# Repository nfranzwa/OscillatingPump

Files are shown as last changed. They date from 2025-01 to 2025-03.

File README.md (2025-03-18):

UCSD MAE 156 Capstone Project

The provided code was developed using Arduino IDE and the Platform.io extension on VS Code.
While it is possible to flash/deploy our software to an ESP32 through other means, we heavily recommend the two for ease of installing dependencies and following subsequent instructions.

# Setup
In order to flash the GPIO ESP or Web ESP, first make a local copy of the most recent version of this repository by clicking `<Code>` and either:

 - Copying and running the command in terminal (requires github cli installation or git)
 - Opening through Github Desktop (requires installing the Github Desktop app)
 - Downloading and extracting the code from a .zip file

The next steps assume you have a local copy of the provided code.

# Installing Libraries

## GPIO ESP

Click the Platform IO icon on the left edge of VS Code, then navigate to `Quick Access > PIO Home > Projects & Configuration`.



Select `Add Existing`.



Navigate to the directory `drive/path/to/repository/OscillatingPump/ESP32_CTRL` and select `Open "ESP32_CTRL`.



Shortly, Platform IO should be setting up the project according to the `platform.ini` file in the selected folder, most importantly installing libraries that are used in the project.

## Web ESP

Open the Arduino sketch named `webesp.ino` located in `/WebappCode/webesp/webesp/`.

Navigate to the library manager.



Search for and install the following libraries:
 - Arduino_JSON by Arduino
 - Async TCP by ESP32Async
 - ESP Async WebServer by ESP32ASync
 - EspSoftwareSerial by Dirk Kaar, Peter Lerup

In the top menu, Navigate to `Sketch > Include Library`, and include the following:
 - WiFi
 - LittleFS



The next step is to install ESP32 LittleFS uploader to the Arduino IDE.

Go to [[https://github.com/earlephilhower/arduino-littlefs-upload/releases]] and download the latest version of `arduino-littlefs-upload-x.x.x.vsix`.

Windows: 
1. In File Explorer, navigate to `C:\Users\<username>\.arduinoIDE\`
2. Create a folder called `plugins` if it doesn't already exist.
3. Move the downloaded `.vsix` file into this folder.

Mac OS: 
1. In Finder, navigate to `~/.arduinoIDE`
2. Create a new folder called `plugins`
3. Move the downloaded `.vsix` file into this folder.

Restart the Arduino IDE, and make sure the plug-in was successfully installed by opening the command palette with `Ctrl/Cmd + Shift + P` and ensuring `Upload LittleFS to Pico/ESP8266/ESP32` is an available command.

# Uploading/Deploying code to the ESP32's

With the environments and libraries set up, one can compile and deploy the code through the following procedures.

## GPIO ESP

On the bottom bar, ensure that the Platform IO project is ESP32_CTRL and you are deploying to the right COM port (leave as `Auto` unless multiple ESP's are connected to same computer).



The code will be compiled and deployed to the ESP32 when pressing the `→` button.
 - one can also compile the code without deploying by pressing the `✓` button.

A new terminal should open within VS Code, displaying compile messages. When the terminal says `Connecting...`
Press and hold the `Boot` button on the ESP until the terminal shows that code is being written to the ESP32.

## Web ESP
First, Go to `Sketch > Show Sketch Folder` and ensure that the `data/` folder from our repository is there. This contains files that are to be uploaded to the ESP32 filesystem.

Open the command palette and run `Upload LittleFS to Pico/ESP8266/ESP32`.

After getting a `Completed upload` message, compile and deploy the sketch to the ESP32 by pressing the `→` button.
 - one can also compile the code without deploying by pressing the `✓` button.

When the terminal says `Connecting...`
Press and hold the `Boot` button on the ESP until the terminal shows that code is being written to the ESP32.

# Troubleshooting code
If the ESP's are consistently not behaving as expected, we provide debugging statements through Serial Monitors, which can be accessed through the Command Palette of both VS Code and Arduino IDE.

Issues to check may include whether an ESP is:
 - constantly restarting (stuck in a boot loop)
 - unable to communicate through serial with the other ESP
 - some particular features are not behaving as expected
 - error codes being thrown by an ESP

The GPIO ESP has an ongoing task that reads the Serial port between the computer and ESP, providing the user with the following inputs and features:

| User Input | Feature |
| --- | --- |
| `debug` | toggles debugging statements for Serial communication between ESPs |
| `cal debug` | toggles debugging statements for during calibration |
| `wave debug` | toggles debugging statements for wave generation |
| `show pm` | prints out the current pressure map vector |
| `m:#.## M:#.##` | manually overwrite the target min and max pressure |
| `c:#` | manually overwrite the calibration state |

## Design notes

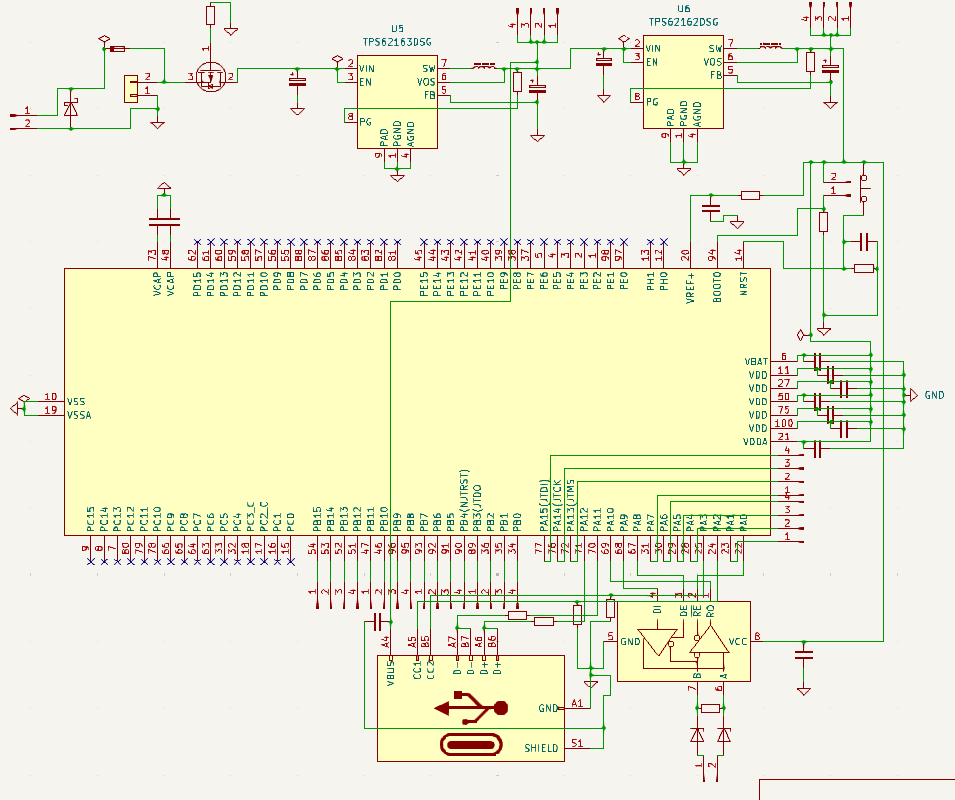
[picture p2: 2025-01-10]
Media/PCB_Schematic.PNG

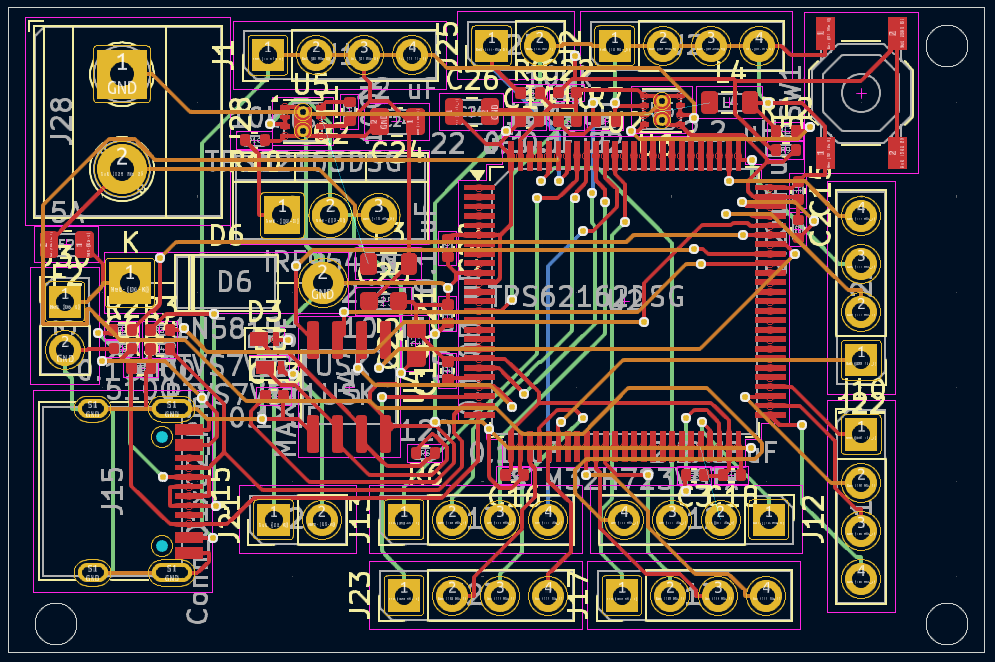
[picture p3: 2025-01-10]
Media/PCB_Layout.PNG

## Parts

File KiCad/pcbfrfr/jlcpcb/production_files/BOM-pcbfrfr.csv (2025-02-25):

Comment | Designator | Footprint | LCSC | Quantity
1000 uF | C5 | CP_Radial_D10.0mm_P5.00mm | C10750 | 1
Barrel_Jack_Switch | J1 | BarrelJack_CLIFF_FC681465S_SMT_Horizontal | C113716 | 1
0.001 uF | C11 | C_0402_1005Metric | C1523 | 1
4.7 uH | L1,L3 | L_Changjiang_FXL0530 | C177246 | 2
AP63205WU | U2 | TSOT-23-6 | C2071056 | 1
SS24 | D1,D3 | D_SMA | C2762829 | 2
Conn_01x02_Pin | J2,J21 | PinHeader_1x02_P2.54mm_Vertical | C2897365 | 2
Conn_01x03_Pin | J9 | PinHeader_1x03_P2.54mm_Vertical | C2897366 | 1
Conn_01x05_Pin | J10,J11,J16,J17,J18,J19,J20,J6 | PinHeader_1x05_P2.54mm_Vertical | C2897368 | 8
Conn_01x19_Socket | J3,J4,J5,J7 | PinHeader_1x19_P2.54mm_Vertical | C2897382 | 4
0.1 uF | C12,C13,C2,C6,C7,C8 | C_0402_1005Metric | C307331 | 6
10 uF | C1 | CP_Radial_D4.0mm_P1.50mm | C43351 | 1
22 uF | C10,C3,C4,C9 | C_0805_2012Metric | C45783 | 4
Conn_01x04_Pin | J12,J13,J14,J15,J8 | PinHeader_1x04_P2.54mm_Vertical | C5116530 | 5
AP63203WU | U1 | TSOT-23-6 | C780769 | 1

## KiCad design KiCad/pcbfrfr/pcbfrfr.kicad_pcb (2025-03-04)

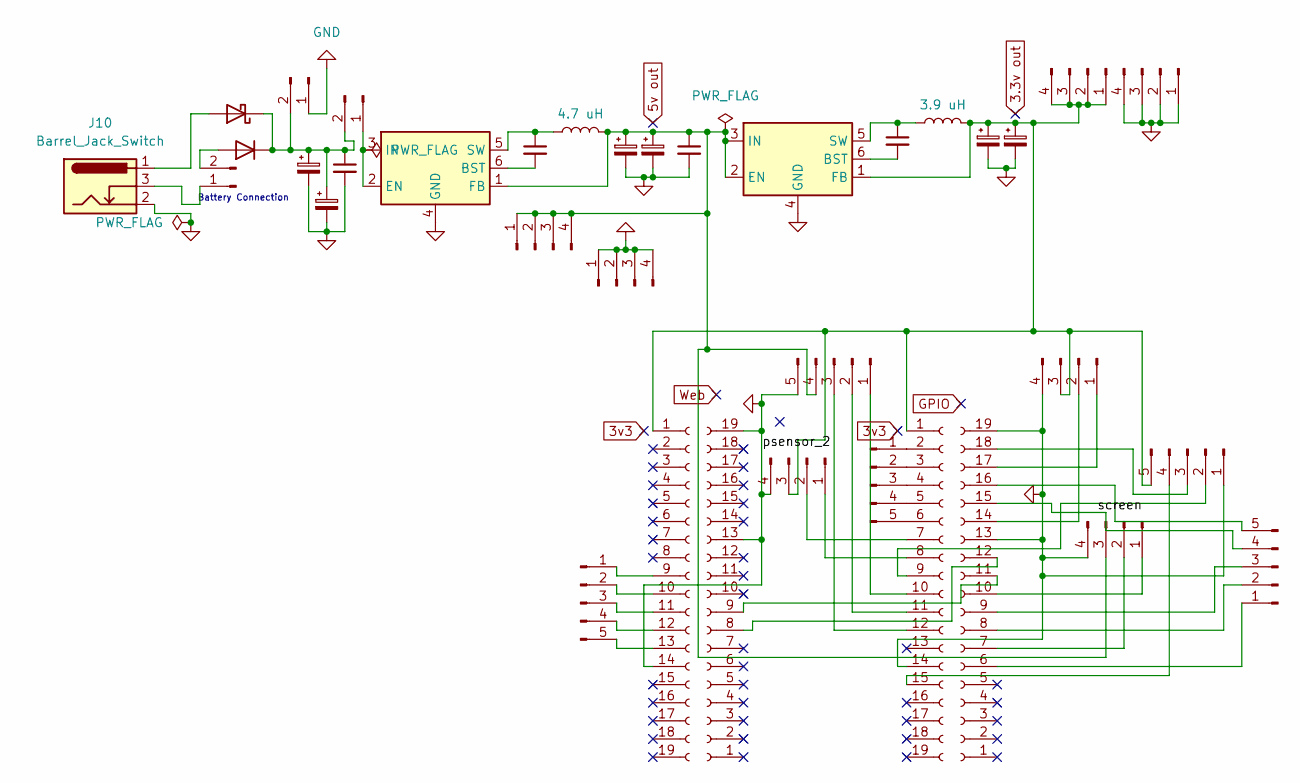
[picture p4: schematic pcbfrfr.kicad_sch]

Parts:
C1: 10 uF; CP_Radial_D4.0mm_P1.50mm
C2, C8: 100 nF; C_0402_1005Metric
C3, C4, C9, C10: 22 uF; C_0805_2012Metric
C5: 1000 uF; CP_Radial_D10.0mm_P5.00mm
C6, C7: 0.1 uF; C_0402_1005Metric
D2: US2AA; D_SMA
D3: SS24; D_SMA
J1, J11, J16, J17, J18: Conn_01x05_Pin; PinHeader_1x05_P2.54mm_Vertical
J2: battery; PinHeader_1x02_P2.54mm_Vertical
J3, J4, J5, J7: Conn_01x19_Socket; PinHeader_1x19_P2.54mm_Vertical
J6, J8, J9, J12, J13, J14, J15: Conn_01x04_Pin; PinHeader_1x04_P2.54mm_Vertical
J10: Barrel_Jack_Switch; BarrelJack_CLIFF_FC681465S_SMT_Horizontal
J21: mtr; PinHeader_1x02_P2.54mm_Vertical
J22: estop; PinHeader_1x02_P2.54mm_Vertical
L1: 4.7 uH; L_Changjiang_FXL0530
L3: 3.9 uH; L_Changjiang_FXL0530
U1: AP63203WU; TSOT-23-6
U2: AP63205WU; TSOT-23-6

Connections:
/screen: J5.15, J17.4
GND: C1.2, C3.2, C4.2, C5.2, C6.2, C7.2, C9.2, C10.2, J1.5, J3.14, J4.14, J5.13, J5.19, J6.4, J7.13, J7.19, J8.4, J9.4, J10.2, J11.1, J13.1, J13.2, J13.3, J13.4, J15.1, J15.2, J15.3, J15.4, J21.1, U1.4 (GND), U2.4 (GND)
unnamed: D2.2 (A), J2.2
unnamed: C1.1, C5.1, C6.1, D2.1 (K), D3.1 (K), J21.2, J22.2
unnamed: D3.2 (A), J10.1
unnamed: J1.1, J4.10
unnamed: J1.2, J4.11
unnamed: J1.3, J4.12
unnamed: C3.1, C4.1, C7.1, J1.4, J9.3, J12.1, J12.2, J12.3, J12.4, L1.2, U1.2 (EN), U1.3 (IN), U2.1 (FB)
unnamed: J2.1, J10.3
unnamed: J4.7, J8.2
unnamed: J4.8, J8.1
unnamed: J5.7, J9.2
unnamed: J5.10, J9.1
unnamed: J5.11, J7.9
unnamed: J5.12, J7.8
unnamed: J5.14, J6.2
unnamed: J5.17, J6.1
unnamed: J4.9, J11.2
unnamed: J5.18, J11.3
unnamed: J4.15, J11.4
unnamed: C9.1, C10.1, J3.1, J4.1, J6.3, J8.3, J11.5, J14.1, J14.2, J14.3, J14.4, L3.2, U1.1 (FB)
unnamed: J4.2, J16.1
unnamed: J4.3, J16.2
unnamed: J4.4, J16.3
unnamed: J4.5, J16.4
unnamed: J4.6, J16.5
unnamed: J5.6, J17.1
unnamed: J5.8, J17.2
unnamed: J5.9, J17.3
unnamed: J5.16, J17.5
unnamed: J3.9, J18.1
unnamed: J3.10, J18.2
unnamed: J3.11, J18.3
unnamed: J3.12, J18.4
unnamed: J3.13, J18.5
unnamed: J22.1, U2.2 (EN), U2.3 (IN)
unnamed: C8.2, U1.6 (BST)
unnamed: C8.1, L3.1, U1.5 (SW)
unnamed: C2.2, U2.6 (BST)
unnamed: C2.1, L1.1, U2.5 (SW)

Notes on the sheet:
Battery Connection

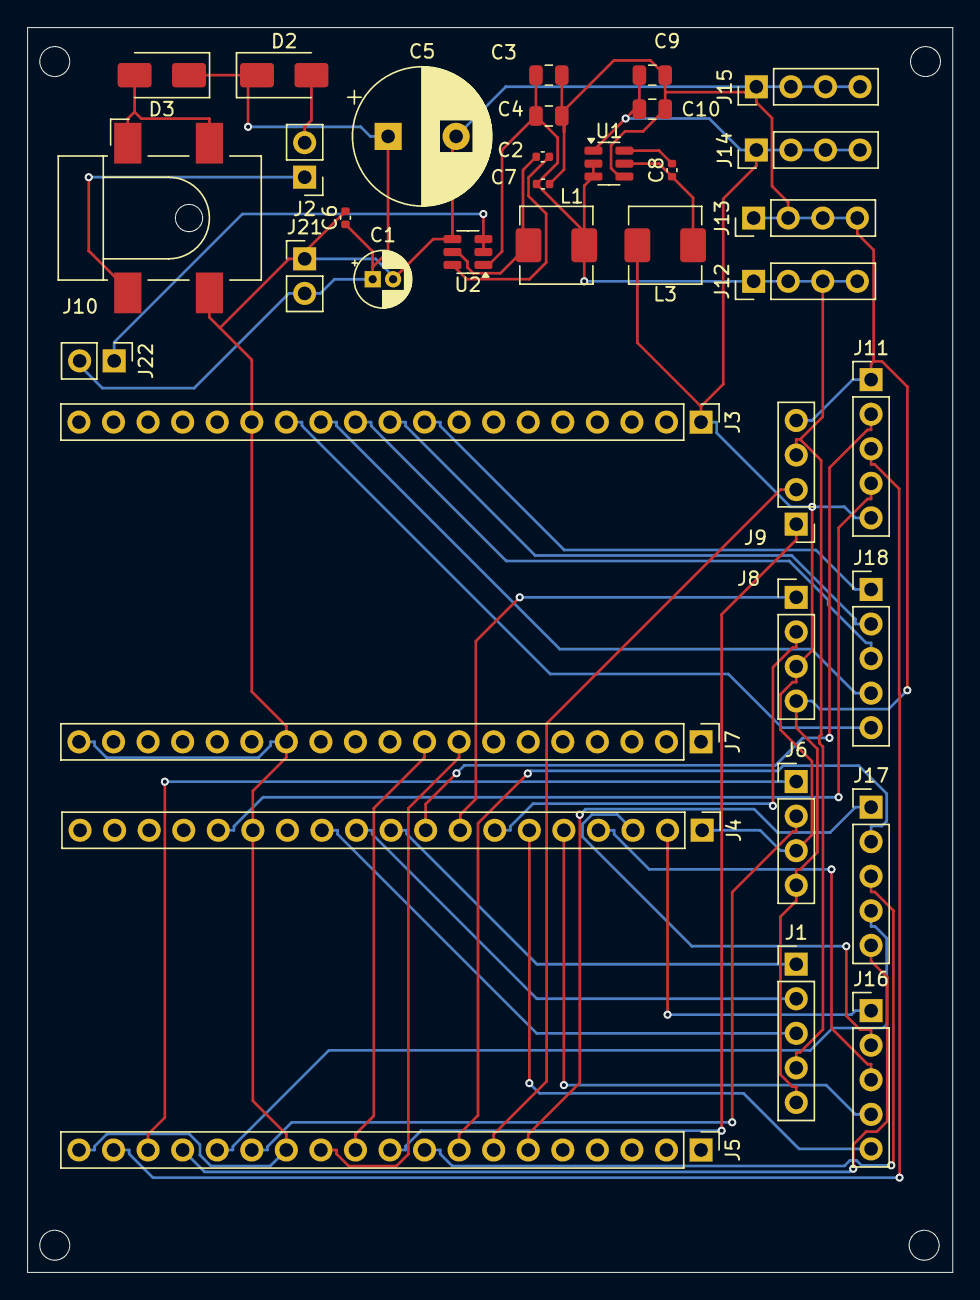
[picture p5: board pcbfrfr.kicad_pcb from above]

Board: 2 copper layers, 68.0 x 91.5 mm, 36 parts (0 on the bottom side), 41 nets.

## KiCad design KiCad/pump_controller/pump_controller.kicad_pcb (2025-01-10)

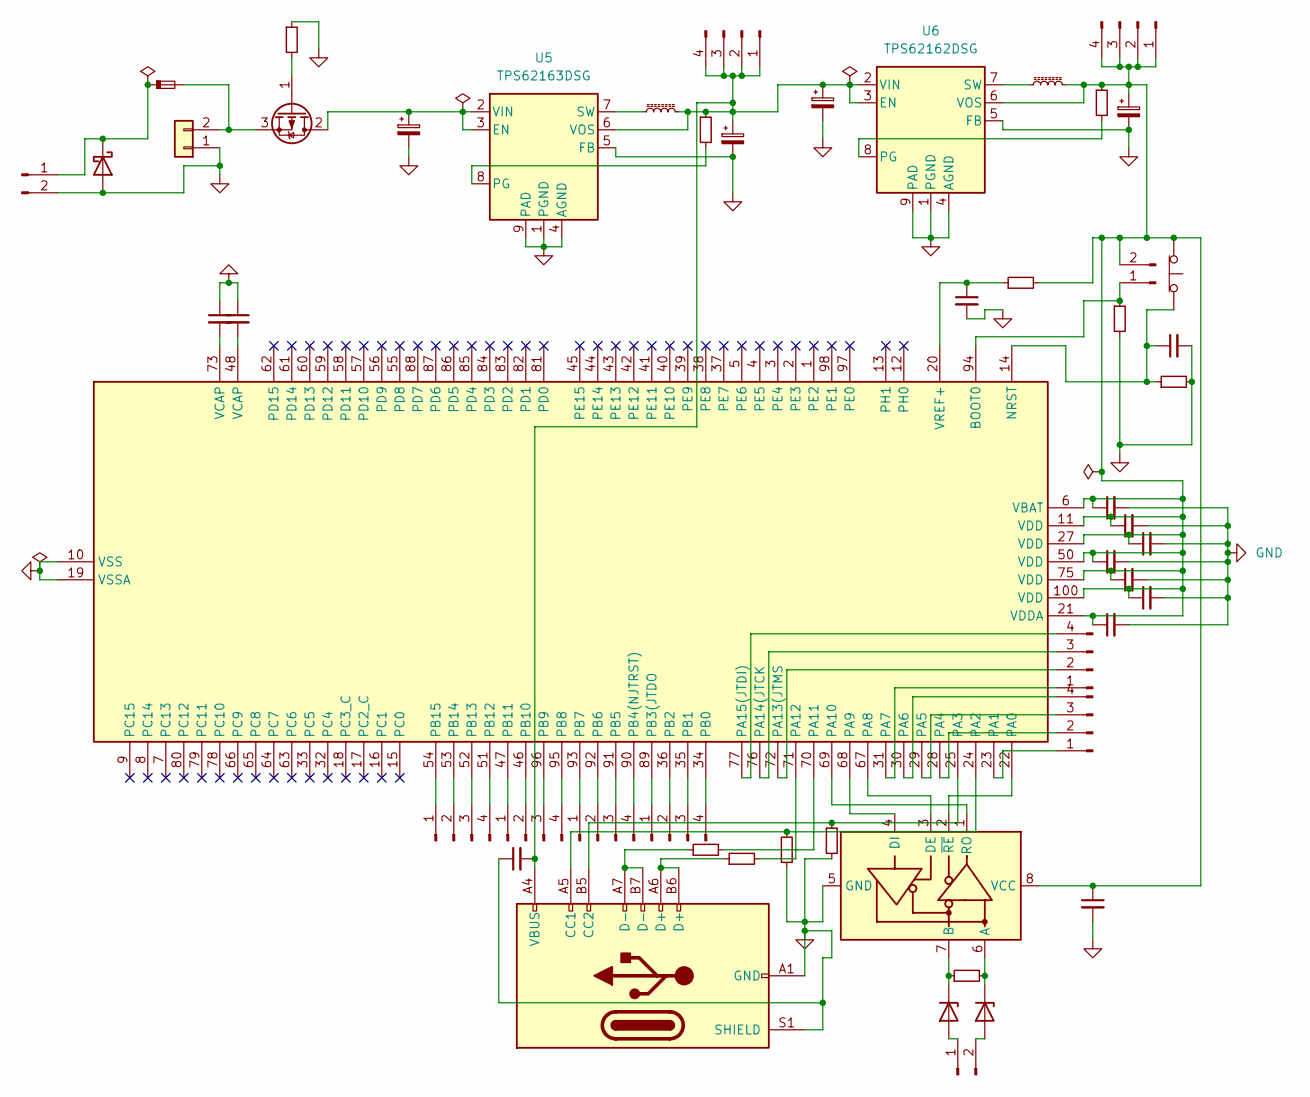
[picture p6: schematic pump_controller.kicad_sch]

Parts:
C2, C3: 2.2 uF; C_0402_1005Metric
C6, C10, C13, C14, C15, C16, C18, C19, C20, C21, C22: 0.1 uF; C_0402_1005Metric
C23, C25: 10 uF; CP_Elec_10x10.5
C24, C26: 22 uF; C_0805_2012Metric
D3, D5: PTVS7V5Z1USK; Nexperia_DSN1608-2_1.6x0.8mm
D6: 1N5819; D_DO-41_SOD81_P10.16mm_Horizontal
F2: 5A; Fuse_0805_2012Metric
J1, J2, J10, J12, J13, J17, J22, J23: Conn_01x04_Pin; PinHeader_1x04_P2.54mm_Vertical
J15: USB_C_Receptacle_USB2.0_14P; USB_C_Receptacle_HRO_TYPE-C-31-M-12
J21, J25, J30: Conn_01x02_Pin; PinHeader_1x02_P2.54mm_Vertical
J28: Conn_01x02; TerminalBlock_Phoenix_MKDS-1,5-2_1x02_P5.00mm_Horizontal
L3, L4: 2.2 uH; L_0805_2012Metric
Q2: IRF9540N; TO-220-3_Vertical
R2, R3, R7: 22; R_0402_1005Metric
R4, R5: 5100; R_0402_1005Metric
R6: 120; R_0402_1005Metric
R8, R9, R10: 10k; R_0402_1005Metric
R11, R12: 100k; R_0402_1005Metric
SW1: SW_Push_Open; SW_SPST_TL3342
U2: STM32H723VGTx; LQFP-100_14x14mm_P0.5mm
U4: MAX3075E; SOIC-8_3.9x4.9mm_P1.27mm
U5: TPS62163DSG; WSON-8-1EP_2x2mm_P0.5mm_EP0.9x1.6mm_ThermalVias
U6: TPS62162DSG; WSON-8-1EP_2x2mm_P0.5mm_EP0.9x1.6mm_ThermalVias

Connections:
GND: C2.1, C3.1, C6.1, C10.2, C13.2, C14.2, C15.2, C16.2, C18.2, C19.2, C20.2, C21.2, C22.2, C23.2, C24.2, C25.2, C26.2, D6.2 (A), J15.A1 (GND), J15.A12 (GND), J15.B1 (GND), J15.B12 (GND), J15.S1 (SHIELD), J28.1, J30.2, R4.1, R5.2, R8.2, R9.2, R10.1, U2.10 (VSS), U2.19 (VSSA), U2.26 (VSS), U2.49 (VSS), U2.74 (VSS), U2.99 (VSS), U4.5 (GND), U5.1 (PGND), U5.4 (AGND), U5.5 (FB), U5.9 (PAD), U6.1 (PGND), U6.4 (AGND), U6.5 (FB), U6.9 (PAD)
unnamed: C2.2, U2.73 (VCAP)
unnamed: C3.2, U2.48 (VCAP)
unnamed: D3.2 (A), J21.1
unnamed: D3.1 (K), R6.1, U4.7 (B)
unnamed: D5.2 (A), J21.2
unnamed: D5.1 (K), R6.2, U4.6 (A)
unnamed: D6.1 (K), F2.1, J30.1
unnamed: C6.2, C24.1, C25.1, J1.1, J1.2, J1.3, J1.4, J15.A4 (VBUS), J15.A9 (VBUS), J15.B4 (VBUS), J15.B9 (VBUS), L3.2, R11.1, U5.6 (VOS), U6.2 (VIN), U6.3 (EN)
unnamed: C13.1, C14.1, C15.1, C16.1, C18.1, C19.1, C20.1, C21.1, C26.1, J2.1, J2.2, J2.3, J2.4, J25.2, L4.2, R7.2, R12.1, SW1.1 (A), U2.6 (VBAT), U2.11 (VDD), U2.21 (VDDA), U2.27 (VDD), U2.50 (VDD), U2.75 (VDD), U2.100 (VDD), U4.8 (VCC), U6.6 (VOS)
unnamed: J10.1, U2.54 (PB15)
unnamed: J10.2, U2.53 (PB14)
unnamed: J10.3, U2.52 (PB13)
unnamed: J10.4, U2.51 (PB12)
unnamed: J12.1, U2.47 (PB11)
unnamed: J12.2, U2.46 (PB10)
unnamed: J12.3, U2.96 (PB9)
unnamed: J12.4, U2.95 (PB8)
unnamed: J13.1, U2.93 (PB7)
unnamed: J13.2, U2.92 (PB6)
unnamed: J13.3, U2.91 (PB5)
unnamed: J13.4, U2.90 (PB4(NJTRST))
unnamed: J15.A5 (CC1), R4.2, U2.24 (PA2)
unnamed: J15.B5 (CC2), R5.1, U2.25 (PA3)
unnamed: J15.A6 (D+), J15.B6 (D+), R3.1
unnamed: J15.A7 (D-), J15.B7 (D-), R2.1
unnamed: J17.1, U2.89 (PB3(JTDO)
unnamed: J17.2, U2.36 (PB2)
unnamed: J17.3, U2.35 (PB1)
unnamed: J17.4, U2.34 (PB0)
unnamed: J22.1, U2.31 (PA7)
unnamed: J22.2, U2.72 (PA13(JTMS)
unnamed: J22.3, U2.76 (PA14(JTCK)
unnamed: J22.4, U2.77 (PA15(JTDI))
unnamed: J23.1, U2.23 (PA1)
unnamed: J23.2, U2.28 (PA4)
unnamed: J23.3, U2.29 (PA5)
unnamed: J23.4, U2.30 (PA6)
unnamed: J25.1, R8.1, U2.94 (BOOT0)
unnamed: F2.2, J28.2, Q2.3 (S)
unnamed: C23.1, Q2.2 (D), U5.2 (VIN), U5.3 (EN)
unnamed: Q2.1 (G), R10.2
unnamed: C22.1, R9.1, SW1.2 (B), U2.14 (NRST)
unnamed: U2.22 (PA0), U4.2 (~RE)
unnamed: U2.67 (PA8), U4.3 (DE)
unnamed: U2.68 (PA9), U4.4 (DI)
unnamed: U2.69 (PA10), U4.1 (RO)
unnamed: R2.2, U2.70 (PA11)
unnamed: R3.2, U2.71 (PA12)
unnamed: C10.1, R7.1, U2.20 (VREF+)
unnamed: R11.2, U5.8 (PG)
unnamed: L3.1, U5.7 (SW)
unnamed: R12.2, U6.8 (PG)
unnamed: L4.1, U6.7 (SW)

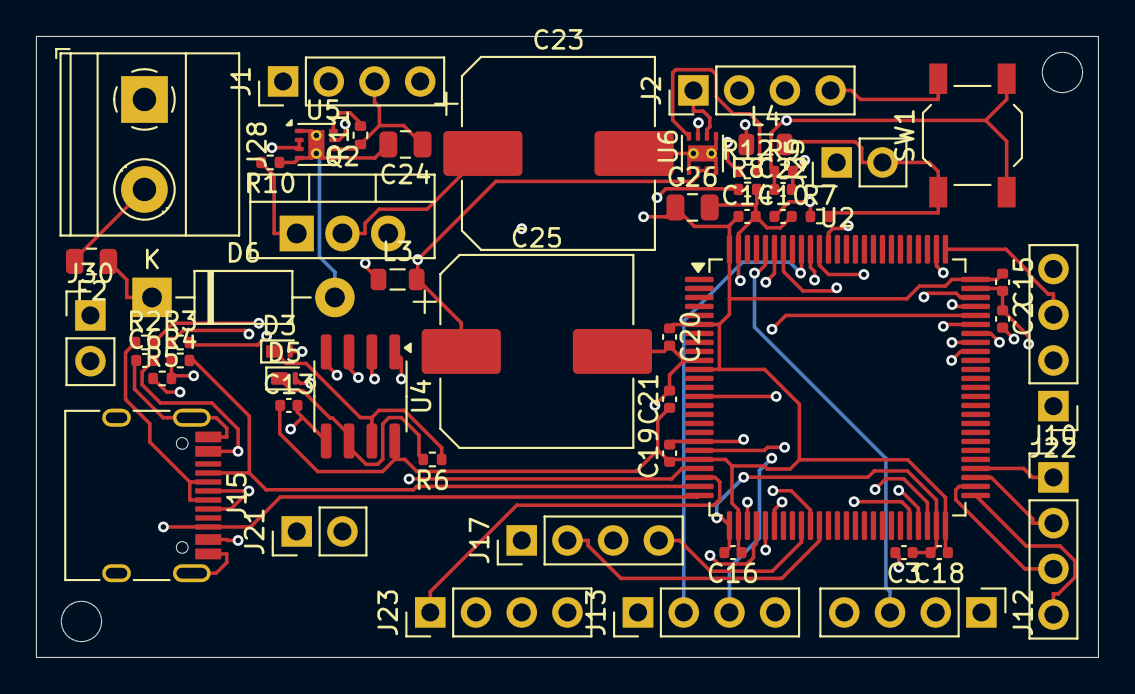
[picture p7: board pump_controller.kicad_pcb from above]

Board: 4 copper layers, 59.0 x 34.5 mm, 53 parts (0 on the bottom side), 54 nets.

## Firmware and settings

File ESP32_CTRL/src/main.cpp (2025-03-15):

#include <Arduino.h>
#include <physicalUI.h>
#include <Sensor.h>
#include <wavegen.h>
#include <motorcontrol.h>
#include <Wire.h> 
#include <LiquidCrystal_I2C.h>
#include <WiFi.h>
#include "sharedData.h"
#include <MightyZap.h>
#include "esp_int_wdt.h"
#include <algorithm>
bool debug      = false; // output to COM port
bool useSensor1 = true;
bool useSensor2 = false;
bool useWave    = true;
bool useLCD     = true;

SharedData sharedData;
String opt_name[] = {"Attack", "Sustain", "Decay", "Rest"};
int ASDR[4] = {1000,2000,100,1500};

// String opt_name[] = {"1","2","3","4"};

//task handles
TaskHandle_t TH_sensor, TH_wavegen, TH_lcd, TH_ui, TH_statusLED, TH_motor=nullptr;
TaskHandle_t TH_calibrate,TH_talk2web, TH_ptest=nullptr;
// task funct prototypes
void TF_sensor(void *pvParams);
void TF_wavegen(void *pvParams);
void TF_ui(void *pvParams);
void TF_lcd(void *pvParams);
void TF_motor(void *pvParams);
void TF_calibrate(void *pvParams);
void TF_talk2web(void *pvParams);
void TF_ptest(void *pvParams);
void TF_status_LED(void *pvParams);

// HardwareSerial Serial2(2);
HardwareSerial mySerial(1);
MightyZap m_zap(&Serial2, MIGHTY_ZAP_EN, 1);

LiquidCrystal_I2C lcd(0x27,20,4);  // set LCD_address: 0x27, num cols: 20, num rows: 4
PhysicalUI ui(CLK,DT,SW);
// PSensor sensor1(P_PIN,"NXP", V_SUPPLY, V_MIN, V_MAX, P_MAX,P_MIN, ADC_RES); 
// PSensor sensor2(P_PIN_NEW,"ABP",V_SUPPLY,V_MIN,V_MAX,P_MAX,P_MIN, ADC_RES);
PSensor sensor1(P_PIN,"I2C",V_SUPPLY,V_MIN,V_MAX,P_MAX,P_MIN, ADC_RES);
// Experimental: give it different waveform shapes: linear, exponential, sine
WaveGenerator wave(sharedData.PWM_min,sharedData.PWM_max,"linear");
MotorControl motor(MIGHTY_ZAP_RX,MIGHTY_ZAP_TX,MIGHTY_ZAP_EN);

void setup() {
    Serial.begin(115200);
    Serial2.begin(115200, SERIAL_8N1, MIGHTY_ZAP_RX, MIGHTY_ZAP_TX);
    Wire.begin();
    mySerial.begin(115200, SERIAL_8N1,RXD1,TXD1);
    // pinMode(P_PIN_OUT,OUTPUT); // physical pin out for pressure
    // moved to sensor.cpp 
    // Wire.beginTransmission(I2C_ADDRESS);
    // if(Wire.endTransmission()==0) Serial.println("Pressure sensor found at 0x28");
    // else Serial.println("sensor not found, check wiring");
    // digitalWrite(P_PIN_OUT,LOW);
    sharedData.pmap.fill(-1.0);
    sharedData.calibration_state=0;
    sharedData.PWM_min = 0;
    sharedData.PWM_max = 4095;
    sharedData.PWM_value= 200;
    memcpy(sharedData.ASDR,ASDR,4*sizeof(int));
    // test values for wave generation w/o calibration
    sharedData.PWM_c_min=000;
    sharedData.PWM_c_max=3000;
    sharedData.P_min=0.05;
    sharedData.P_max=1.0;
    for (int i =sharedData.PWM_c_min=000; i <= sharedData.PWM_c_max; i++){
        sharedData.pmap[i] = (i - sharedData.PWM_c_min) * (0.6f / (sharedData.PWM_c_max - sharedData.PWM_c_min));
    }
    ui.begin();
    ui.setOptions(sharedData.ASDR, opt_name, 100);
    sensor1.begin();
    motor.setMotor(&m_zap);
    motor.begin();
    // wave.updateParams(ASDR,sharedData.PWM_min,sharedData.PWM_max);
    lcd.init();
    lcd.backlight();
    lcd.setBacklight(128);
    ui.setLCD(&lcd);
    // create tasks
    xTaskCreatePinnedToCore(TF_sensor   ,"Sensor Task"  ,4000   , &sensor1, 2, &TH_sensor , 0);
    xTaskCreatePinnedToCore(TF_talk2web ,"Web Comm Task",100000 , nullptr , 3, &TH_talk2web,0);
    xTaskCreatePinnedToCore(TF_wavegen  ,"Wavegen Task" ,6000   , &wave   , 1, &TH_wavegen, 0);
    xTaskCreatePinnedToCore(TF_lcd      ,"LCD Task"     ,5000   , &lcd    , 1, &TH_lcd    , 1);
    xTaskCreatePinnedToCore(TF_ui       ,"UI Task"      ,6000   , &ui     , 1, &TH_ui     , 0);
    // xTaskCreatePinnedToCore(TF_status_LED,"statLED Task",4000   , nullptr , 0, &TH_statusLED,0);
    xTaskCreatePinnedToCore(TF_motor    ,"Motor Task"   ,4000   , &motor  , 0, &TH_motor  ,0);
    xTaskCreatePinnedToCore(TF_calibrate,"Calib. Task"  ,8000   , &motor  , 0, &TH_calibrate,0);
    // xTaskCreatePinnedToCore(TF_ptest    ,"testP Task"   ,2000   , nullptr , 0, &TH_ptest  ,0);

}

void loop() {
    //FreeRTOS handles task scheduling so this can remain empty
    String serialInput;
    float value;
    if(Serial.available()){
        serialInput=Serial.readStringUntil('\n');
        //if there's a new message that matches, rewrite the variables
        if(serialInput.startsWith("debug")){
            debug=!debug;
            Serial.printf("Updated: debug=%d",debug);
            // Consider adding the rest of the debug toggles here
        }
        if (sscanf(serialInput.c_str(), "mp:%f", &value) == 1) {
            // Successfully parsed the message
            Serial.printf("Updated: test = %-4.4f\n",value);
            Serial.printf("mapPos(%2.2f)=%d\n",(float) value,mapPos(value));
        }
        if (sscanf(serialInput.c_str(),"c:%d",&sharedData.calibration_state)){
            Serial.printf("MANUAL: Calibration state %d\n",sharedData.calibration_state);
        }
        if (serialInput.equals("wave debug")){
            sharedData.wave_debug=!sharedData.wave_debug;
            Serial.printf("Updated: wave debug=%d",sharedData.wave_debug);
        }
        if (serialInput.equals("slope debug")){
            sharedData.slope_debug=!sharedData.slope_debug;
            Serial.printf("Updated: slope debug=%d",sharedData.slope_debug);
        }
        if (serialInput.equals("cal debug")){
            sharedData.cal_debug=!sharedData.cal_debug;
            Serial.printf("Updated: cal debug=%d",sharedData.cal_debug);
        }
        if (serialInput.equals("show pm")){
            int i = 0;
            for (const float& value : sharedData.pmap) {
                Serial.printf("Index %-4d: %+2.3f\n", i, value);
                i++;
            }
        }
        if(sscanf(serialInput.c_str(),"m:%f M:%f",&sharedData.P_min,&sharedData.P_max)){
            Serial.printf("Updated: Pm=%2.2f, PM=%2.2f\n",sharedData.P_min,sharedData.P_max);
        }
    }
    if(sharedData.slope_debug) Serial.printf("%s: Value:%2.2f\n",wave.getTransition(),sharedData.PWM_value);
    //otherwise continue changing the sharedData.P_test as normal
    delay(100);
    // delay(100);
}

void TF_talk2web(void* pvParams){
    // if theres a message sent to the serial port
    Serial.println("Start T2W Task");
    for(;;){
        if(mySerial.available()){
            sharedData.prev_state=sharedData.calibration_state;
            // Serial.println("start reading");
            vTaskDelay(pdMS_TO_TICKS(10));
            String msg = mySerial.readStringUntil('\n');
            // String msg="help";
            if(debug) Serial.println("Received "+msg);
            //if the new message matches format, rewrite the variables
            //MinP, MaxP, S, R, A/D, calibration_state, manual position
            
            if (sscanf(msg.c_str(), "%f,%f,%d,%d,%d,%d,%d",
                &sharedData.P_minH2O, &sharedData.P_maxH2O,&sharedData.ASDR[1],
                &sharedData.ASDR[3],&sharedData.ASDR[0],
                &sharedData.calibration_state,&sharedData.PWM_manual) == 7
                ) {
                sharedData.ASDR[2]= sharedData.ASDR[0];
                if(sharedData.calibration_state==1 && sharedData.prev_state==2){
                    sharedData.calibration_state=2;
                    if(debug) Serial.println("Received 1, I was 2");
                }
                if(sharedData.calibration_state==3 && sharedData.prev_state==2){
                    sharedData.calibration_state=3;
                }
                //convert input (H2O) to psi
                sharedData.P_min=sharedData.P_minH2O/70.307;
                sharedData.P_max=sharedData.P_maxH2O/70.307;
                // Successfully parsed the message
                //print statement for update
                if(debug){
                    Serial.printf("Pmin%-2.2f Pmax%-2.2f A/D:%d S:%d R%d\n",
                        sharedData.P_min,sharedData.P_max,sharedData.ASDR[0],sharedData.ASDR[1],sharedData.ASDR[3]);    
                }
            }
        }
        if(debug){
            Serial.printf("%f,%d,%d\n",sharedData.P_current ,sharedData.calibration_state,sharedData.error);
        }
        mySerial.printf("%f,%d,%d\n",sharedData.P_current*70.0307,sharedData.calibration_state,sharedData.error);
        // Serial.println("T2W end of loop");
        vTaskDelay(pdMS_TO_TICKS(100));
    }
}

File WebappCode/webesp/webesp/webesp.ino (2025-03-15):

#include <Arduino.h>
#include <WiFi.h>
#include <AsyncTCP.h>
#include <ESPAsyncWebServer.h>
#include <LittleFS.h>
#include <Arduino_JSON.h>

#define TXD1 19
#define RXD1 18

const int greenLedPin = 26;  // Main LED
const int redLedPin = 25;
// Use Serial1 for UART communication
// Add these variables to track changes
String prev_minpresVal = "0";
String prev_maxpresVal = "20";
String prev_attacktime = "500";
String prev_sustVal = "1200";
String prev_resttime = "1200";
String prev_calibrationstate = "0";

// Last time data was sent to peripheral
unsigned long lastPeripheralUpdate = 0;
const long peripheralUpdateInterval = 100;  // 100ms between serial sends

// Force periodic updates even without changes
unsigned long lastForcedUpdate = 0;
const long forcedUpdateInterval = 2000;  // 2 seconds

HardwareSerial mySerial(2);


const char *ssid = "ESP32";
const char *password = "ucsdpumpguest";

String calibrationstate = "0";
int calint = 0;  // Global variable to track calibration state for LED status
int errorcode = 0;
float pressure = 0.0;
float attacktimefloat = 0;
float SustValfloat = 0;
float resttimefloat = 0;
float currentSensorPressure = 0.0;  // Global variable to store current pressure

unsigned long previousMillis = 0;
const long blinkInterval = 500;  // Blink interval in milliseconds (0.5 second)
int greenLedState = LOW;
int redLedState = LOW;

// Flag to indicate web UI values have changed
bool valuesChanged = false;

AsyncWebServer server(80);
AsyncEventSource events("/events");

String minpresVal = "0";
String maxpresVal = "20";
String attacktime = "500";
String sustVal = "1200";
String recording = "0";
String resttime = "1200";

String success;

const char *PARAM_INPUT = "value";
unsigned long lastTime = 0;
unsigned long timerDelay = 60;
bool seconditer = false;


void initLittleFS() {
  if (!LittleFS.begin()) {
    Serial.println("An error has occurred while mounting LittleFS");
  } else {
    Serial.println("LittleFS mounted successfully");
  }
}

void initWiFi() {
  
  WiFi.softAP(ssid, password);
  delay(100);
  IPAddress IP(192, 168, 1, 85);
  IPAddress NMask(255, 255, 255, 0);
  WiFi.softAPConfig(IP, IP, NMask);
  Serial.print("AP IP address: ");
  Serial.println(IP);
}

// Improved sendToPeripheral function with buffer clearing
void sendToPeripheral() {
  // Clear any pending data first
  while (mySerial.available()) {
    mySerial.read();  // Clear buffer
  }

  int MinPresValfloat = minpresVal.toInt();
  int attacktimeInt = attacktime.toInt();
  int SustValInt = sustVal.toInt();
  int MaxPresValfloat = maxpresVal.toInt();
  int resttimeInt = resttime.toInt();
  calint = calibrationstate.toInt();  // Update the global variable

  // Print debug message to main serial
  Serial.println("Sending to peripheral: " + String(MinPresValfloat) + "," + String(MaxPresValfloat) + "," + String(SustValInt) + "," + String(resttimeInt) + "," + String(attacktimeInt) + "," + String(calint));

  mySerial.print(MinPresValfloat);
  mySerial.print(",");
  mySerial.print(MaxPresValfloat);
  mySerial.print(",");
  mySerial.print(SustValInt);
  mySerial.print(",");
  mySerial.print(resttimeInt);
  mySerial.print(",");
  mySerial.print(attacktimeInt);
  mySerial.print(",");
  mySerial.print(calint);
  mySerial.print("\n");

  // Update previous values
  prev_minpresVal = minpresVal;
  prev_maxpresVal = maxpresVal;
  prev_attacktime = attacktime;
  prev_sustVal = sustVal;
  prev_resttime = resttime;
  prev_calibrationstate = calibrationstate;

  lastPeripheralUpdate = millis();
  valuesChanged = false;
}

// Handler for readings endpoint - moved outside of loop
void handleReadings(AsyncWebServerRequest *request) {
  char sensorpresString[15];
  dtostrf(currentSensorPressure, 1, 6, sensorpresString);
  int attacktimeInt = attacktime.toInt();
  int sustValInt = sustVal.toInt();
  int resttimeInt = resttime.toInt();
  String json = String(sensorpresString) + "," + String(attacktimeInt) + "," + String(sustValInt) + "," + String(resttimeInt);
  request->send(200, "text/plain", json.c_str());
}

void setup() {
  Serial.begin(115200);
  initWiFi();
  Serial.println();
  initLittleFS();
  pinMode(greenLedPin, OUTPUT);
  pinMode(redLedPin, OUTPUT);
  mySerial.begin(115200, SERIAL_8N1, RXD1, TXD1);

  server.on("/", HTTP_GET, [](AsyncWebServerRequest *request) {
    request->send(LittleFS, "/index.html", "text/html");
  });
  server.serveStatic("/", LittleFS, "/");

  // Register the readings endpoint handler HERE in setup, not in loop
  server.on("/readings", HTTP_GET, handleReadings);

  // Modified handlers to send values immediately
  server.on("/MinPressure", HTTP_GET, [](AsyncWebServerRequest *request) {
    String inputMessage;
    if (request->hasParam(PARAM_INPUT)) {
      inputMessage = request->getParam(PARAM_INPUT)->value();
      minpresVal = inputMessage;
      valuesChanged = true;

      // Send immediately without waiting for interval
      sendToPeripheral();
    } else {
      inputMessage = "No message sent";
    }
    request->send(200, "text/plain", "OK");
  });

  server.on("/MaxPressure", HTTP_GET, [](AsyncWebServerRequest *request) {
    String inputMessage;
    if (request->hasParam(PARAM_INPUT)) {
      inputMessage = request->getParam(PARAM_INPUT)->value();
      maxpresVal = inputMessage;
      valuesChanged = true;

      // Send immediately without waiting for interval
      sendToPeripheral();
    } else {
      inputMessage = "No message sent";
    }
    request->send(200, "text/plain", "OK");
  });

  server.on("/AttackTime", HTTP_GET, [](AsyncWebServerRequest *request) {
    String inputMessage;
    if (request->hasParam(PARAM_INPUT)) {
      inputMessage = request->getParam(PARAM_INPUT)->value();
      attacktime = inputMessage;
      valuesChanged = true;

      // Send immediately without waiting for interval
      sendToPeripheral();
    } else {
      inputMessage = "No message sent";
    }
    request->send(200, "text/plain", "OK");
  });

  server.on("/record", HTTP_GET, [](AsyncWebServerRequest *request) {
    String inputMessage;
    if (request->hasParam(PARAM_INPUT)) {
      inputMessage = request->getParam(PARAM_INPUT)->value();
      recording = inputMessage;
    } else {
      inputMessage = "No message sent";
    }
    request->send(200, "text/plain", recording);
  });

  server.on("/RestTime", HTTP_GET, [](AsyncWebServerRequest *request) {
    String inputMessage;
    if (request->hasParam(PARAM_INPUT)) {
      inputMessage = request->getParam(PARAM_INPUT)->value();
      resttime = inputMessage;
      valuesChanged = true;

      // Send immediately without waiting for interval
      sendToPeripheral();
    } else {
      inputMessage = "No message sent";
    }
    request->send(200, "text/plain", "OK");
  });
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

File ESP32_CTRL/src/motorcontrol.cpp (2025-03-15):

#include <MightyZap.h>
#include <Arduino.h>
#include <sharedData.h>
#include <motorcontrol.h>
#define ID_NUM 0
#define MIN_POS 100

// ESP32 has multiple hardware serial ports (UART)
// We'll use Serial2 for MightyZap communication
int maxPosition = 2000;  // Default max position
float frequency = 0.75;   // Default frequency in Hz
unsigned long lastSensorRead = 0;  // For timing sensor readings
unsigned long cycleStartTime = 0;  // For tracking cycle timing
const float DUTY_CYCLE = 0.4;  // 40% duty cycle

// Calculate speed needed for symmetric movement within duty cycle
int MotorControl::calculateSpeed(int distance, float freq) {
  // Total period = 1/frequency
  float totalPeriod = 1.0 / freq;
  
  // Active time is 40% of the period, split equally between forward and back
  float activeTime = totalPeriod * DUTY_CYCLE;
  // Each movement (forward or back) gets half of the active time
  float moveTime = activeTime / 2.0;
  
  // Calculate required speed in MightyZap units (mm/sec * 10)
  float requiredSpeed = (float)distance / moveTime / 10.0;
  
  // Constrain to valid speed range
  return (int)constrain(requiredSpeed, 1, 1023);
}

void MotorControl::updateParameters() {
  int distance = maxPosition - MIN_POS;
  int speed = calculateSpeed(distance, frequency);
  m_zap->GoalSpeed(ID_NUM, speed);
  Serial.printf("Updated speed to: %d\n", speed);
}


void MotorControl::begin() {
  // Initialize Serial2 for MightyZap communication
  // Serial2.begin(32, SERIAL_8N1, MIGHTY_ZAP_RX, MIGHTY_ZAP_TX);
  
  // Initialize MightyZap
  m_zap->begin(32);
  
  // Set ADC resolution to 12 bits
  // analogSetWidth(12);
  
  updateParameters();
  cycleStartTime = millis();
  int currentPos = m_zap->presentPosition(ID_NUM);
  Serial.printf("Initial position: %d\n", currentPos);
}

/*
only moves motor to target position under specific calibration state
*/
void TF_motor(void* pvParams) {
  MotorControl* motor= (MotorControl*) pvParams;
  Serial.println("Motor Task");
  for(;;) {
    sharedData.P_min=sharedData.P_minH2O/70.307;
    sharedData.P_max=sharedData.P_maxH2O/70.307;
    if(sharedData.calibration_state==2){
      motor->m_zap->GoalPosition(ID_NUM, 4095 - sharedData.PWM_value);
    }
    else if(sharedData.calibration_state==3){
      motor->m_zap->GoalPosition(ID_NUM,4095-sharedData.PWM_manual);
    }
    // sharedData.PWM_current=motor->m_zap->presentPosition(ID_NUM);
    vTaskDelay(pdMS_TO_TICKS(4));
  }
}

/**
 * @brief Calibrate initial motor position and pressure estimates
 * Stage 0: Initial message (detach pump)
 * Stage 1: Moving to initial position
 * Stage 2: Waiting for pump reattachment
 * Stage 3: Retracting to minimum pressure
 * Stage 4: Finding precise P_min position
 * Stage 5: Sweeping to P_max
 * Stage 6: Finalizing calibration
 * 
 * @param pvParams The MightyZap motor address
 */
void TF_calibrate(void* pvParams) {
  bool debug = false;
  MotorControl* motor = (MotorControl*) pvParams;
  int stage = 0;
  unsigned long lastCommandTime = 0;
  bool commandSent = false;
  int currentPosition = 0;
  int targetPosition = 0;
  int startrange=20;
  // Register with watchdog
  #ifdef CONFIG_ESP_TASK_WDT_ENABLED
      esp_task_wdt_add(NULL);
  #endif
  
  Serial.println("Calibration Task Started");
  for(;;) {
    debug = sharedData.cal_debug;
    if(debug) {
      Serial.printf("state: %d, Stage: %d, CMD time: %5f\n", 
        sharedData.calibration_state, stage, 
        sharedData.calibration_state==2 ? 0: (float) (millis()-lastCommandTime));
    }
    
    // Reset stage if calibration state is reset
    if(sharedData.calibration_state == 0) {
      stage = 0;
      commandSent = false;
      int idle_PWM=2000;
      sharedData.PWM_value=motor->m_zap->presentPosition(ID_NUM);
      if(sharedData.PWM_value>=idle_PWM+10 || sharedData.PWM_value<=idle_PWM-10) motor->m_zap->GoalPosition(ID_NUM,idle_PWM);
    }
    // running calibration
    if(sharedData.calibration_state == 1) {
      switch(stage) {
        case 0: // Initialization
          // Only print message once
          if(!commandSent) {
            Serial.println("Starting calibration. Please detach pump.");
            commandSent = true;
            lastCommandTime = millis();
          }
          
          // Wait 3 seconds for user to detach pump
          if(millis() - lastCommandTime > 3000) {
            // Move to next step
            stage = 1;
            commandSent = false;
            if(debug) Serial.printf("End of stage 0, moving to stage 1\n");
          }
          break;
          
        case 1: // Move to initial position
          if(!commandSent) {
            Serial.println("Moving to initial position");
            targetPosition = 2500;
            motor->m_zap->GoalPosition(ID_NUM, targetPosition);
            commandSent = true;
            lastCommandTime = millis();
          }
          
          // Check if reached position or timeout
          sharedData.PWM_value = 4095 - motor->m_zap->presentPosition(ID_NUM);
          if(abs(sharedData.PWM_value - targetPosition) <= startrange || millis() - lastCommandTime > 3000) {
            if(debug) Serial.printf("Retract CMD fulfilled: %d\n", sharedData.PWM_value);
            Serial.println("Motor reached position or timeout. Please reattach pump.");
            lastCommandTime = millis();
            stage = 2;
            commandSent = false;
            if(debug) Serial.printf("End of stage 1, moving to stage 2\n");
          }
          break;
          
        case 2: // Wait for user to reattach pump
          if(millis() - lastCommandTime > 3500) {
            stage = 3;
            commandSent = false;
            if(debug) Serial.printf("End of stage 2, moving to stage 3\n");
          }
          break;
          
        case 3: // Move back until minimum sensor reading
          if(!commandSent) {
            if(debug) Serial.println("Send CMD: retract until Pmin");
            commandSent = true;
          }
          
          // retract if over pressurized
          if(sharedData.P_current >= sharedData.P_min) {
            if(debug) Serial.println("Retracting until hitting minimum sensor pressure");
            // Still above min pressure, continue moving
            targetPosition = 4095;
            motor->m_zap->GoalPosition(ID_NUM, targetPosition);
            
          } else {
            // Reached target pressure
            sharedData.PWM_value = 4095 - motor->m_zap->presentPosition(ID_NUM);
            if(debug) Serial.printf("retract CMD finished: P_min ~ %d\n", sharedData.PWM_value);
            motor->m_zap->GoalPosition(ID_NUM, 4095-sharedData.PWM_value);
            motor->m_zap->GoalSpeed(ID_NUM, 10); // Set to slow speed
            if(debug) Serial.printf("Minimized speed, end of stage 3\n");
            stage = 4;
            commandSent = false;
          }
          break;
          
        case 4: // Find P_min position precisely
          if(!commandSent) {
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

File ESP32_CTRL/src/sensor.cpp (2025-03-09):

#include <sensor.h>
#include <Arduino.h>
#include "sharedData.h"
#include <Wire.h>
#include <filter_lib.h>
#include <motorcontrol.h>

void PSensor::begin(){
    analogReadResolution(12); //default 12 bits (0~4095)
    analogSetAttenuation(ADC_11db);
    // if(SENSOR_TYPE=="I2C") pinMode(EOC,INPUT);
}

float PSensor::readPressure(){
    float adc_value=analogRead(SENSOR_PIN);
    float voltage= (adc_value/ADC_RESOLUTION)*V_MAX;
    if (SENSOR_TYPE=="NXP"){
        /* from datasheet of MP3V5010 sensor sold by NXP:
        https://www.nxp.com/docs/en/data-sheet/MP3V5010.pdf
        V_OUT=V_S*(.09*P+0.08) \pm V_S*(0.09*P_error * temp_factor)
        ignoring the noise section:
        → P = (V_OUT/V_S-.08)/.09
        The constant value would give a reading of .2 V at P=0 kPa
        
        HOWEVER, following code is run with the transfer function updated as:
        V_OUT=V_S*(.09*P+0.05) → P = (V_OUT/V_S-.05)/.09
        */
       return (voltage/V_SUPPLY -.05)/.09;
    }
    else if (SENSOR_TYPE=="ABP"){
        /* From datasheet of ABP Analog pressure sensor:
        https://www.mouser.com/datasheet/2/187/HWSC_S_A0013047928_1-3073376.pdf
        Using the analog version, 
        V_out= .8*V_SUPPLY/(P_MAX-P_MIN) * (P-P_MIN) + .10*V_SUPPLY
        
        Set P_MAX=10 kPa, P_MIN=0 kPa
        */
       return (voltage-0.1*V_SUPPLY)*(P_MAX-P_MIN)/(.8*V_SUPPLY)+P_MIN;
    }
    else if(SENSOR_TYPE=="I2C"){
        /*
            TODO: UPDATE WHICH SENSOR THIS IS
            THIS IS PSI READINGS
        */
        // send request for measurements
        Wire.beginTransmission(I2C_ADDRESS);
        int stat = Wire.write(CMD, 3);
        if(Wire.endTransmission()==0){
            // Serial.println("Pressure sensor found at 0x28\n");
        }
        else Serial.println("Sensor not found\n");
        Wire.requestFrom(I2C_ADDRESS, 7); //7 byte total
        vTaskDelay(5);
        if(Wire.available()>=7){
            // Serial.println("Sensor found?");
            int i=0;
            Wire.requestFrom(I2C_ADDRESS, 7);
            for (i = 0; i < 7; i++)
            {
                data[i] = Wire.read();
            }
            press_counts = data[3] + data[2] * 256 + data[1] * 65536; // calculate digital pressure counts
            pressure = ((press_counts - outputMin) * (pmax - pmin)) / (outputMax - outputMin) + pmin;
            return pressure; // PSI VALUE
        }
        else{
            Serial.println("No msg read\n");
            return P_MAX;
        }
    }
    else if (SENSOR_TYPE=="I2C2B"){
        int praw=0;
        Wire.requestFrom(I2C_ADDRESS, 2);
        if (Wire.available() >= 2) {
            uint8_t highByte = Wire.read();
            uint8_t lowByte = Wire.read();
            praw= (highByte << 8) | lowByte;
        } else {
            Serial.println("No data received.");
        }
        return maptopsi(praw)*6.89746;
        
    }
    else if(SENSOR_TYPE=="DUMMY"){
        return sharedData.P_test;
    }
    else{
        return P_MAX;
    }
    //CONSIDER: adding a constrain() to value
}

float PSensor::maptopsi(int value){
    if (value < -16383) value = -16383;
    if (value > 16383)  value = 16383;
    // Perform the mapping:
    // We need to scale from a 32766 range (-16383 to 16383) to a 200 range (-100 to 100)
    float result = (value / 16383.0) * 100.0;
    result = result * 0.0145;
    return result;
}

float PSensor::filter(float measurement){
    bool useLPF=true;

    if(useLPF){
        return LPF.filter(measurement);
    }
    else{
        /*
        Digital filter to apply to the sensor measurements.
        Currently trying to implement a Kalman filter.
        */
        
        float prediction = past_estimate;
        float prediction_err= past_error+NOISE_PROC; // prediction error
        
        float gain_kalman= prediction_err/(prediction_err+NOISE_MEAS);
        float estimate= prediction+gain_kalman*(measurement-prediction);
        float estimate_err = (1-gain_kalman)*prediction_err;
        
        past_estimate=estimate;
        past_error=estimate_err;
        return estimate;
    }
}

void TF_sensor(void *pvParams){
    //generic data is sent (void*) so we type cast
    PSensor* sensor =(PSensor*) pvParams;
    for(;;){
        // WARNING: remember that I2C sensor readings are in PSI

        sharedData.P_current=sensor->filter(sensor->readPressure());
        // Serial.printf("Sensor data:%-5f\n",sharedData.P_current);
        vTaskDelay(pdMS_TO_TICKS(15)); //66.7Hz
    }
}

void mapPressure(void* pvParams) {
    MotorControl* motor= (MotorControl*) pvParams;
    for(;;){
      sharedData.pmap[motor->m_zap->presentPosition(ID_NUM)]=sharedData.P_current;
      vTaskDelay(pdMS_TO_TICKS(33));//30Hz
    }
}

void cleanArray(std::array<float,4096>& pmap, int startIdx, int endIdx) {
    // Skip processing if the range is invalid
    if (startIdx >= endIdx) return;
    
    // First pass: Find the first valid value
    int firstValid = -1;
    for (int i = startIdx; i <= endIdx; i++) {
        if (pmap[i] != -1.0f) {
            firstValid = i;
            break;
        }
    }
    
    // Return if no valid points were found
    if (firstValid == -1) return;
    
    // Second pass: Ensure monotonicity (never decreasing)
    float currentMax = pmap[firstValid];
    
    // Set all invalid entries before firstValid to the first valid value
    for (int i = startIdx; i < firstValid; i++) {
        pmap[i] = currentMax;
    }
    
    // Process the rest of the array
    for (int i = firstValid + 1; i <= endIdx; i++) {
        if (pmap[i] == -1.0f) {
            // Replace invalid values with the current maximum
            pmap[i] = currentMax;
        } else {
            // If valid but less than current maximum, update to current maximum
            if (pmap[i] < currentMax) {
                pmap[i] = currentMax;
            } else {
                // Update current maximum if we found a larger value
                currentMax = pmap[i];
            }
        }
    }
}
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

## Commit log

2025-01-13 Agasthya Code for website
    [data.csv]
2025-01-21 Agasthya new webapp code
    [data.csv]
2025-02-06 Basic open-loop implementation
    Add adjustable target waveform with PWM,
    interface for browsing and alternating values,
    implemented safeguard against SAVING invalid values for waveform properties.
    Framework for pressure sensor and filter; needs to be tested
2025-02-18 Physical UI V1
    LCD display of sensor data, target value, and interaction with rotary encoder to change between view modes (edit, view, temp).
    TODO: task handlers with FreeRTOS to run LCD on separate core, as it currently interrupts the rotary encoder detecting correct input
    [main.cpp, physicalUI.cpp, physicalUI.h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]
2025-02-19 Agasthya client side
    [data1.csv]
2025-02-20 UI fixed, Free RTOS implemented
    Updated UI to run encoder, sensor, and wave generator on separate code from LCD. UI modified to change between view modes (ASDR, soon other modes) by short clicks, and edit parameters by holding down + rotating.
    [main.cpp, physicalUI.cpp, physicalUI.h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]
2025-02-21 Motor + Physical UI Consolidated
    🎉 Motor controlled by ASDR and adjustable via physical UI
2025-02-25 phys UI + barebones for I2C sensor
2025-02-26 Agasthya i couldnt tweak the motor sorry
2025-02-26 Pressure mapping and rudimentary calibration code
    Still needs a feature to allow user to trigger when to start the calibration
2025-02-26 i fixed the world
    [webesp.ino]
2025-02-27 Calibration Modes and communication w/ web esp
2025-03-06 Calibration and dummy sensor code, serial comm NEEDS fixs
    core 0 is being hogged by the talk2web task, as it is taking too long to listen. additionally need to optimize the priorities and memory given to each task. Start breaking code into smaller functions, replace vTaskDelay() with taskYIELD() in appropriate places
    [main.cpp, motorcontrol.cpp, sensor.cpp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]
2025-03-06 added barebones serial comm test between esp + maybe arduino
2025-03-07 Updated GPIO for new I2C sensor
    Stable release
2025-03-07 dummy serial code updated
    now can input values and toggle to read current value
2025-03-07 edits, everything works but breaks without lcd or motor connected
2025-03-08 i dont have time for the name
    more thorough code for error feedback and status LED
    [main.cpp, motorcontrol.cpp, physicalUI.cpp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]
2025-03-08 pressure map update
    added initial values for testing waveform and pressure map without calibrating
2025-03-09 finally have communication
    code still fighting on shared values,
    calibration needs to be ironed out
2025-03-09 added some serial testing
    user can input "mp:%f" for debugging mapPos(float pressure) to test the pressure map (you receive an integer PWM position for desired pressure)
    user can input "c:%d" for manually changing calibration state
2025-03-09 🎉 Monotonic pressure mapping + Calibration code
    Waveform also works, but logic for setting the PWM_last_min during loops must be correct
    [main.cpp, motorcontrol.cpp, physicalUI.cpp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]
2025-03-11 publish error code to Web ESP
    also a little bit of experimenting for changing waveform shape
    [main.cpp, motorcontrol.cpp, sharedData.h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]
2025-03-11 idle position for when calibration state=0
2025-03-12 updated pins for PCB
